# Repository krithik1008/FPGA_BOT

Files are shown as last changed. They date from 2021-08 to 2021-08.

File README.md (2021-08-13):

# FPGA BOT

FPGA based line follower bot using DE0-nano (Altera cyclone 4E FPGA) along with integration of various sensors and components like line follower, TCS-3200 color sensor, motor drivers, Xbee, etc. to traverse an arena and complete a set of specified tasks.

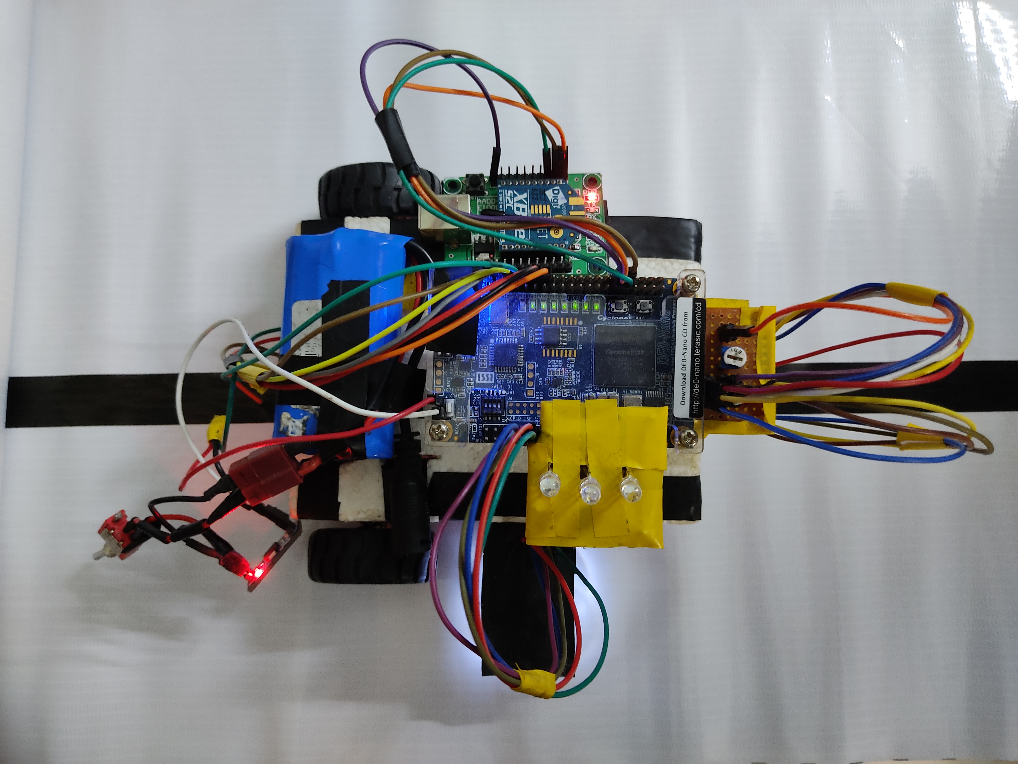
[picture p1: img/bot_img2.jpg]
<br>
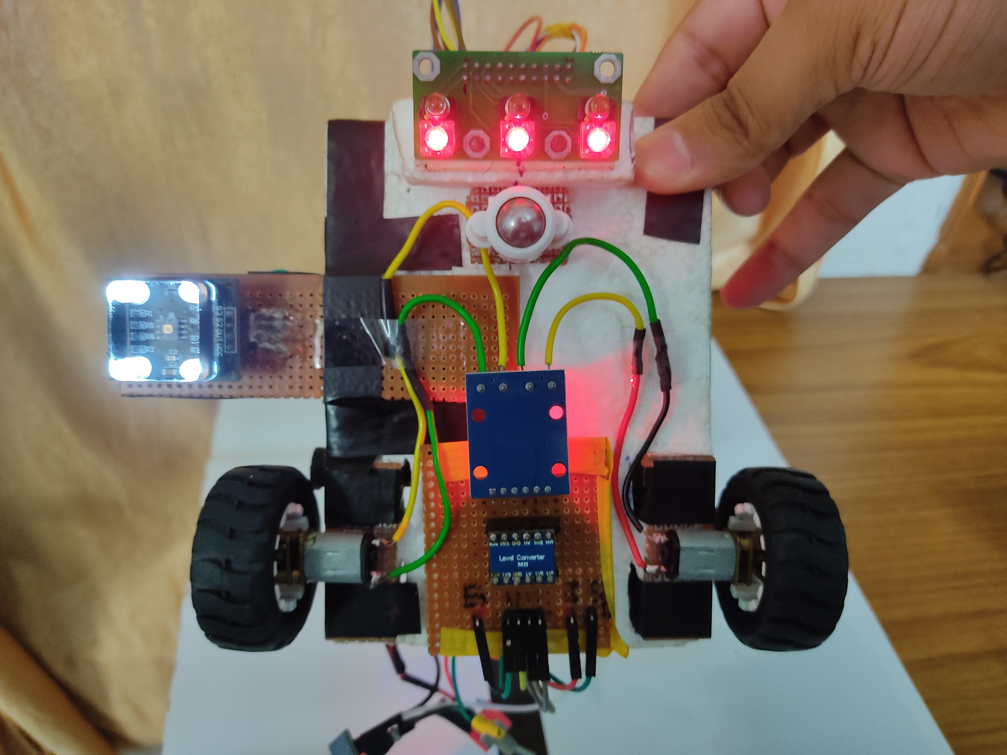
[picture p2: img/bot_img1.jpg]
<br><br>

Note: Using the code from this project may not work in other projects as this project is developed with specification and constraints of this bot in mind.

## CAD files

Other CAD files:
db/stp2_auto_stripped.stp
output_files/stp4.stp
db/stp1_auto_stripped.stp
db/stp3_auto_stripped.stp
db/stp4_auto_stripped.stp

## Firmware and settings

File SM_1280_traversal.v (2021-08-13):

/*
	Team ID		:	SM#1280
	Author list	: 	Krithik sankar, Ayush Mittal
	Filename		: 	SM_1280_traversal.v
	Theme			:	Sankatmochan Bot
	Functions	:  Traversal
	Global Variables : None
	
*/
	
	
/*
	Function Name		:	Traversal	
	States				:	path_block, start, measure, cleft, cright, fleft, fright, decision,
								uturn, calculation_mpu, calculation_ssu, calculation_pu, calculation_w,
								scan_traversal, scan_init, luturn, unit_path_init, idle, s1, s2, s3,
								turn_delay, run_end
	
	
	General Comment	:	It implements the line following algorithm (measure, cleft, cright, fleft, fright), calculates the entry node and exit node of each manufacturing 
								unit after receiving the blocked path list from the message unit(calculation_mpu, calculation_ssu, calculation_pu, calculation_w,),it also implements 
								the dijkstra algorithm with the help of idle,s1,s2,s3 states , along with that it translates the path mapped out by the dijkstra algorithm in to actual mechanical motions 
								with the help of decision state.it also autocorrects the orientation of the bot after it reaches one of the units to scan for faults.
								
	Logic					:  It first wait for the bot to receive the blocked path in the path_block state. It then moves to the start state waiting for the key0 to be pressed , once, the key is 
								pressed calculations are made to speculate the path ,entry node of each manufacturing unit in such a way that path from entry to exit node is in clockwise direction.
								We have installed the color sensor on the right side of the bot therefore scanning the units in the clockwise direction will always result in the sensor to be on the side where the patches are present.
								After all the calculations are made, dijkstra algorithm is executed to calculate the path from current node to the entry node of MPU or PU.Here the trick is that source node is 
								initialised to be the entry node of the unit rather than the current node of the bot , this helps us to read the path to be followed directly from the path array in a straight forward fashion rather than by conventional backtracking the 
								the destination point. After the path is ready then the bot moves to the decision state where we have mapped each node in to an individual entity which translates the path from the path array to the actual motions 
								depending upon the previous node , current node and the next immediate node. Once the bot reaches the entry point of any unit then the code moves to the scan_init state where the path array is re-initialized 
								according to calculations made at the starting of the traversal to begin with scanning of the unit, along with that the bot also choose the entry point of the next unit it has to go after finishing up the scanning. 
								It then corrects its orientation with the help of decision state and after that it scan the unit with the help of scan_traversal,cleft,and cright states.Once it reaches the exit node of the 
								unit, again dijkstra is implemented to find the way to the SSU unit. After reaching the ssu unit and scaning the same from the logic mentioned above, the code again follows the same logic described above untill the variables pu_count,
								mpu_count and w_count becomes zero. These variables are decremented each time the bot scans the corresponding unit , and are incremented in the case of fire or when the faults are more then 3.After scanning a unit , 
								the bot will traverse towards the SSU unit irrespective of the number of faults it is carrying.
								
								
							
								
	Example Call	:	   It is the central module where all other modules are called.
	

	
*/
module traversal(
	//adc variables (line follower)
	adcin,			//dout from the adc module 
	cs,
	mhz32,			//adc runs with 3.2 MHz clock
	din,
	
	//motor input output variables
	khz100,			//using 100kHz clock to run motor at 1KHz
	la,				//left motor
	lb,
	ra,				//right motor
	rb,
	
	motor_3v,		//using a GPIO pin for 3.3v ref of motor driver
	  
	//node tansmission variables
	node_detect,
	node_count,
	
	//for staring traversal when key 0 is pressed 
	key0,
	
	// accelerometer variables
	accel,      // value from accelerometer  
	accelvalid,
	
	//uart receiver
	blocked_path,				// number of bytes to be transmitted
	RX_DATA_DONE,
	
	//message variables
	in_scan,
	unit,
	is_stop,
	pu_count,
	mpu_count,
	w_count,
	red_flagg
);
// red detection 
input red_flagg;

//uart receiver
input  [15:0] blocked_path; // array which tells which path is blocked 0th index tells the state of bridge path, other indexes conveys that the corresponding path is blocked if the value is 1.
input RX_DATA_DONE;			 // if one then data is ready in blocked_path

// acceleromerter variables 
input [15:0] accel ;
reg [31:0] accel_delay=0;			//a small amount of delay has been introduced so that bot can reach to the slope of bridge 
output reg accelvalid=1;											
										 
//when node is detected these variables helps in conveying this to message module 
output reg node_detect=0;			//1 if a node is detected
output reg [5:0] node_count=0;	
reg node=0;								//temp variable for node detection 
  

// key0 implementation
input key0;

//delay variables
reg [23:0] wait_count=0;			// random delay variabe
reg [23:0] ddelay=490000; 			// bot detects the node in the very beginnig, because of which turning left/right to the next path becomes difficult, 
											// to overcome that we have introdoced a small delay so that the bot crosses the node first after detection and then execute the turn left / turn right protocol
reg [23:0] slope_count=0;			// sometimes, the bot completely stops while descending down the bridge because ,reverse braking is executed continously , and the speed of the bot reduces to 0 on the slope itself
											// this variable is used to prevent that state. 

//adc variables
input adcin;
input mhz32;			//adc runs with 3.2 MHz clock
output cs;				//chip select
output din;
wire [11:0] center;	//center sensor values
wire [11:0] left;		//left sensor values
wire [11:0] right;	//right sensor values



//adc instantiation for line following
ADC_controller utt1(
	.sclk(mhz32),			
	.dout(adcin),
	.rst(0),
	.cs(cs),
	.din(din),
	.ADC_DATA_CH1(right),
	.ADC_DATA_CH2(center),
	.ADC_DATA_CH3(left)
);

//motor variables
reg [7:0] turn_pwn	=	37;
reg [7:0] turn_pwn_r	=	37;

reg [7:0] base_pwm 	= 	39;	//base speed (pwm) of motors 
reg [7:0] offset1 	= 	37;		//base will be increased by offest1 
reg [7:0] offset2		= 	39;		//base will be decreased by offest2 
reg [7:0] pwml=0;          //pwm value of left motor (input to motor module)
reg [7:0] pwmr=0;			   //pwm value of right motor (input to motor module)
reg dirl=1'b1;				   //direction of motor (forward/backward), 1 for forward
reg dirr=1'b1;				 

input khz100;				//100KHz clock to make it 1KHz for motor
output la,lb,ra,rb;

output motor_3v=1;		//using a GPIO pin for 3.3v ref of motor driver
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

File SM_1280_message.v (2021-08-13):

/*
	Team ID		:	SM#1280
	Author list	: 	Krithik sankar, Ayush Mittal
	Filename		: 	SM_1280_message.v
	Theme			:	Sankatmochan Bot
	Function		:	message	
	Global Variables : None
		
*/
	

/*

Function Nmae :	message
Input 		  :	CLOCK,sensor,node_detect,node_no, in_scan,unit, is_stop,
Output 		  :	O_TX_SERIAL ,S3,led1 ,led2 ,led3 ,mpu_second, pu_count, mpu_count,w_count

Logic			  :	It implements the fault detection and resolving algorithm, along with that it manages the messages to be transmitted . Faults in each unit are managed and stored seperately
						in variables. Each time the bot enters the unit it discards or detect a paticular fault depending upon the data stored in these variables. 

Example Call  :	module message(

						CLOCK(CLOCK),
						.O_TX_SERIAL(O_TX_SERIAL),
							
						.sensor(sensor),
						.S3(S3),
							
						.node_detect(node_detect),     
						.node_no(node_no),  
					
						.led1(led1),		
						.led2(led2),
						.led3(led3),
							
						.in_scan(in_scan),
						.unit(unit),
						.is_stop(is_stop),
						
						.pu_count(pu_count),
						.mpu_count(mpu_count),
						.w_count(w_count)
					);	

*/
module message(

	//uart variables
	input CLOCK,
	output O_TX_SERIAL,

	
	//colour sensor variables
	input sensor,
	output S3,
	output S2,
	
	//node detection varialbles, input from traversal module
	input node_detect,     // if 1 then node detected
	input [5:0] node_no,   // node number, detected from traversal module 
	
	//led variables
	output reg [2:0] led1,			//To assign color to the led
	output reg [2:0] led2,
	output reg [2:0] led3,			// all these are mapped to hardware pins
	
	
	//traversal variables
	input in_scan,					// input from traversal , indicates whether the bot is scanning or not
	input [2:0] unit,				// tells which unit ,the bot is scanning
	input is_stop,					// marks the end of run to blink white led
	
	
	output reg [7:0] pu_count,
	output reg [7:0] mpu_count,		// output to traversal , conveys whether the bot has to come back or not.
	output reg [7:0] w_count,
	output reg red_flag
);
				
	
//uart variables
reg [95:0] 	data=0;				// data to be transmitted
reg [95:0] 	trans_data;			// temperorary variable used to construct message
reg [3:0] 	no_of_bytes;		// coveys the no. of bytes to be transmitted to the uart module 
reg 			valid_uart=0;		// if 1 then uart module will transmit the data
wire 			done;					// if 1 then uart module has transmitted the data			
reg [2:0] transmit_count=0;	// no. of times the uart module has to transmit the same data 

//color sensor variables
wire [2:0] 	color;						// color from color_sensor module
reg [2:0] 	prev_color=3'b000;		//to keep track of previous color given by the sensor 
reg [2:0] 	prev_color_trans=3'b000;// prev color transmitted
wire 			valid_color;				// indicates ,data from color sensor is valid 
reg 			measure=1;					// reset for color senor 

 

//led variables
reg led_valid=0;							// used to indicate whether the message has to be transmitted or not through zigbee
reg [2:0]temp_led=3'b111;				// temporary variable for color checking

reg [4:0] mpu_patch_count=0;			//  all these variables, count the number of patches detected in a single scan 
reg [4:0] pu_patch_count=0;			//
reg [4:0] w_patch_count=0;				//

reg [4:0] mpu_color=0;					//  keeps a track of the number of patches in the corresponding unit
reg [4:0] pu_color=0;					//
reg [4:0] w_color=0;						//
reg [4:0] temp=6;

reg [5:0] track=0;						// tracks the number of patches for which message has been transmitted in a single scan , cant be greater then 3 

//stop run variables
reg [2:0] stop_cnt=0;					// variables used for white led glowing 
reg [19:0] stop_count=0;				//

reg [26:0] master=0;						//variables used for white led glowing 


initial
begin
	led1=3'b111;			//initially the led does not glow
	led2=3'b111;
	led3=3'b111;
	
	pu_count=1;
	mpu_count=1;
	w_count=1;
	transmit_count=0;
	red_flag=0;							//for detecting fire
end

main utt( .CLOCK(CLOCK),.TX_BYTE(data), .TX_DATA_VALID(valid_uart),.O_TX_SERIAL(O_TX_SERIAL), .O_TX_DONE(done),.no_of_bytes(no_of_bytes),.transmit_count(transmit_count));
	
colour_sensor utt1( .sensor(sensor), .measure(measure), .clk(CLOCK), .S3(S3), .S2(S2),	.color(color), .valid(valid_color));



localparam scan				=	4'b0000;  // decides the unit to be managed depending upon the input (unit) from the traversal module
localparam mpu					=	4'b0001;	 // manages MPU unit 
localparam pu					=	4'b0010;	 // manages PU unit 
localparam w					=	4'b0011;	 // manages W unit 
localparam ssu					=	4'b0100;  // manages SSU unit 
localparam on					=	4'b0101;	 // state to implement white led
localparam off					=	4'b0110;	 // state to implemet white led

reg [7:0] nsst	=	scan;
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
